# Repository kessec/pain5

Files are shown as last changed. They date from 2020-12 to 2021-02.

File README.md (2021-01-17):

## The Pain 5 Keyboard! 
Pain-5 Logo

A 5-key keyboard that depends on pressing keys in combination! Supports up to 120 keys and/or macros!

### Features
- Licensed under [Solderpad Hardware License v2.1](https://solderpad.org/licenses/SHL-2.1/)
- ATMEGA32U4 Based.
- USB-C Support.
- QMK compatible.
- One-handed operation.
- 0603 components (good for hand placing!).
- Comes with all the files for JLCPCB production.

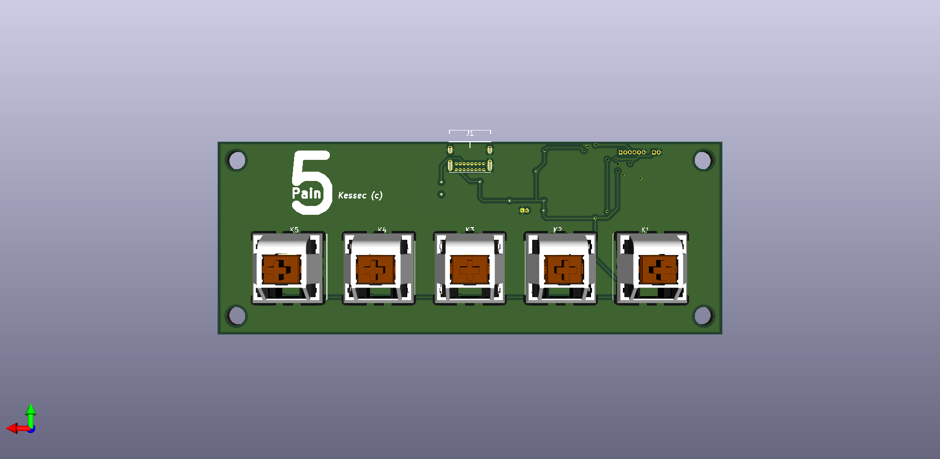
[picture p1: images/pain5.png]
3D Model Front

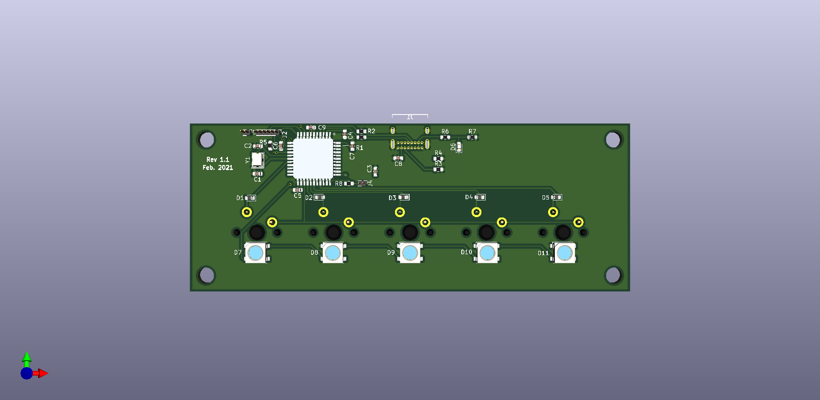
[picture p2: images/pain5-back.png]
3D Model Back


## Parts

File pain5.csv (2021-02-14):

Comment | Designator | Footprint | LCSC
22pF | C1,C2 | Capacitor_SMD:C_0603_1608Metric | C1653
10uF | C3 | Capacitor_SMD:C_0603_1608Metric | C96446
0.1uF | C4,C5,C6,C7 | Capacitor_SMD:C_0603_1608Metric | C170140
4.7uF | C8 | Capacitor_SMD:C_0603_1608Metric | C19666
1uF | C9 | Capacitor_SMD:C_0603_1608Metric | C15849
D_Schottky | D1,D2,D3,D4,D5 | Diode_SMD:D_0603_1608Metric | C316054
POWER_LED | D6 | LED_SMD:LED_0603_1608Metric | C72043
USB_C_Receptacle_USB2.0 | J1 | Type-C:USB_C_GCT_USB4085
ISP Programming | J2 | Connector_PinHeader_1.00mm:PinHeader_1x06_P1.00mm_Vertical
Reseter | J3 | Connector_PinHeader_1.00mm:PinHeader_1x02_P1.00mm_Vertical
KEYSW | K1,K2,K3,K4,K5 | Switch_Keyboard_Cherry_MX:SW_Cherry_MX_PCB_1.00u
22 | R1,R2 | Resistor_SMD:R_0603_1608Metric | C23345
5.1k | R3,R4 | Resistor_SMD:R_0603_1608Metric | C23186
10K | R5 | Resistor_SMD:R_0603_1608Metric | C25804
1K | R6 | Resistor_SMD:R_0603_1608Metric | C21190
2K | R7 | Resistor_SMD:R_0603_1608Metric | C22975
MCU-ATMEGA32U4-MUR(VQFN44) | U1 | ATMEGA-32U4-MUR:MCU-ATMEGA32U4-MUR_VQFN44 | C45874
Crystal_GND24 | Y1 | Crystal:Crystal_SMD_3225-4Pin_3.2x2.5mm | C13738

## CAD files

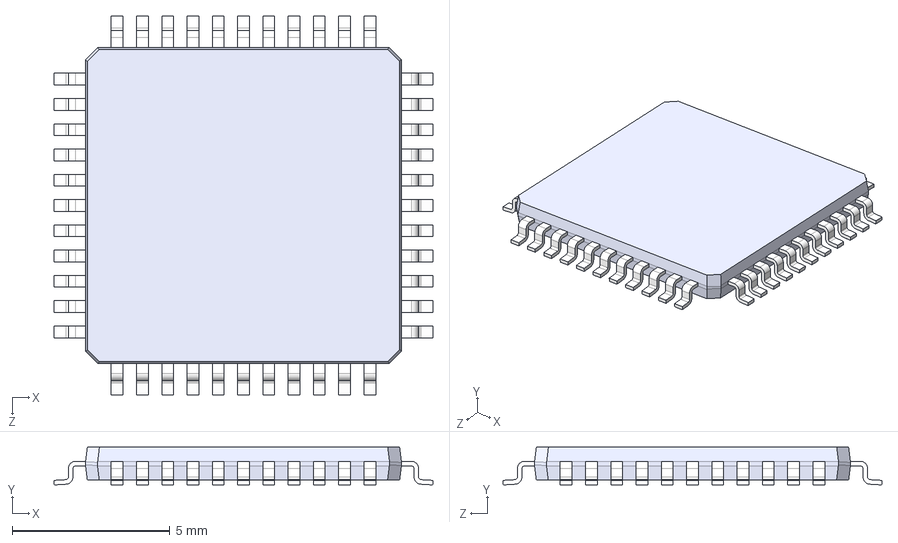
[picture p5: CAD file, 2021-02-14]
3D/ATMEGA32U4-AU.step
12.0 x 1.20 x 12.0 mm

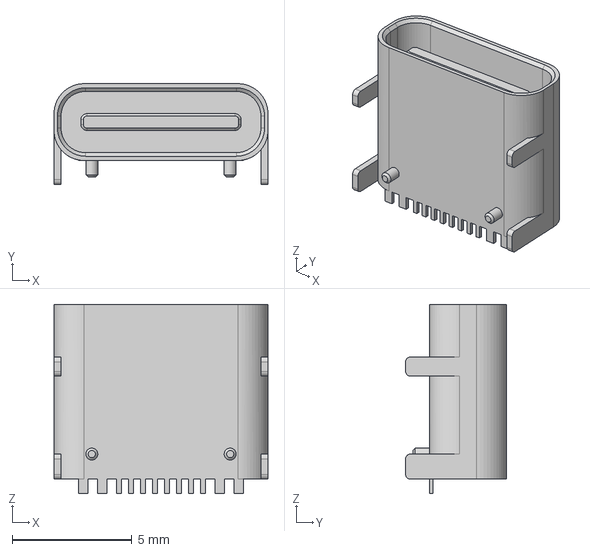
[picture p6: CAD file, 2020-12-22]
components/Type-C/HRO TYPE-C-31-M-12.step
8.94 x 4.21 x 7.90 mm

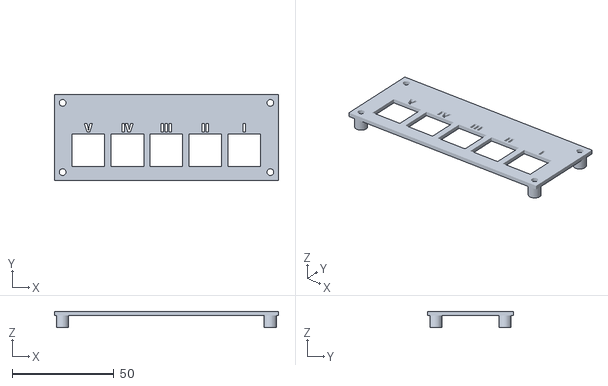
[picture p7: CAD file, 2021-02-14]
STL/Topv4.stl
110.0 x 42.0 x 8.00

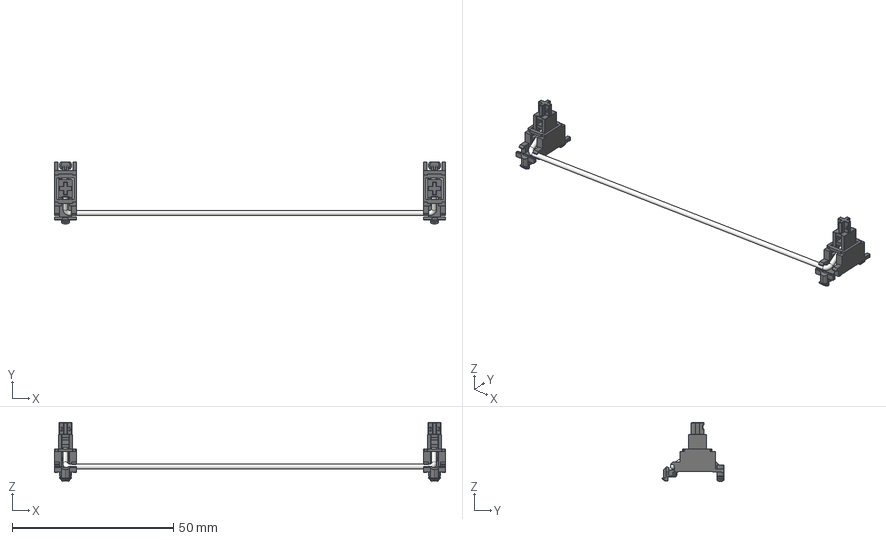
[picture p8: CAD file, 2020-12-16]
Switch_Keyboard/packages3d_src/Mounting_Keyboard_Stabilizer/Stabilizer_Cherry_MX_7u.FCStd
121.1 x 19.2 x 18.3 mm
Bar
Stabilizer_Key_
Stabilizer_Base_
Stabilizer_Key
Stabilizer_Base

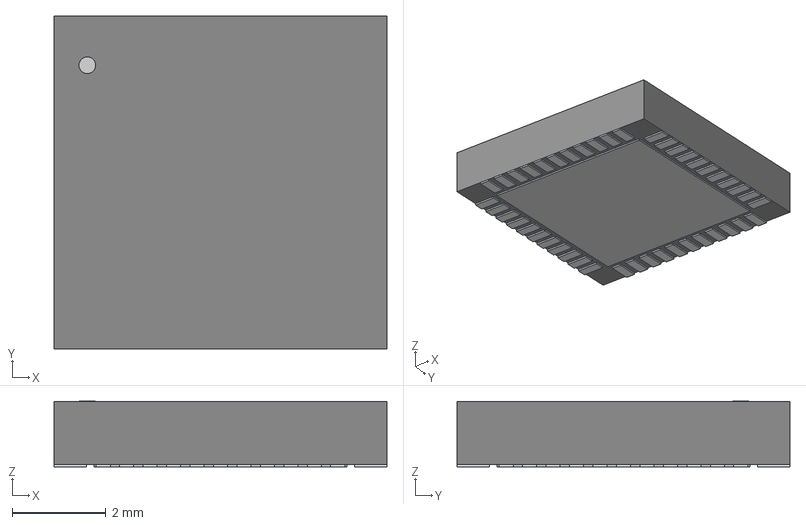
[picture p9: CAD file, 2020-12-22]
3D/44PW_ATM.step
7.10 x 7.10 x 1.40 mm

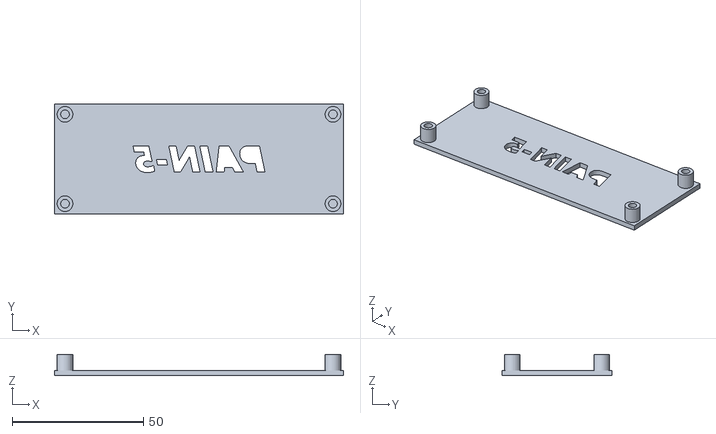
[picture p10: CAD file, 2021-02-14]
STL/Basev4.stl
110.0 x 42.0 x 8.00

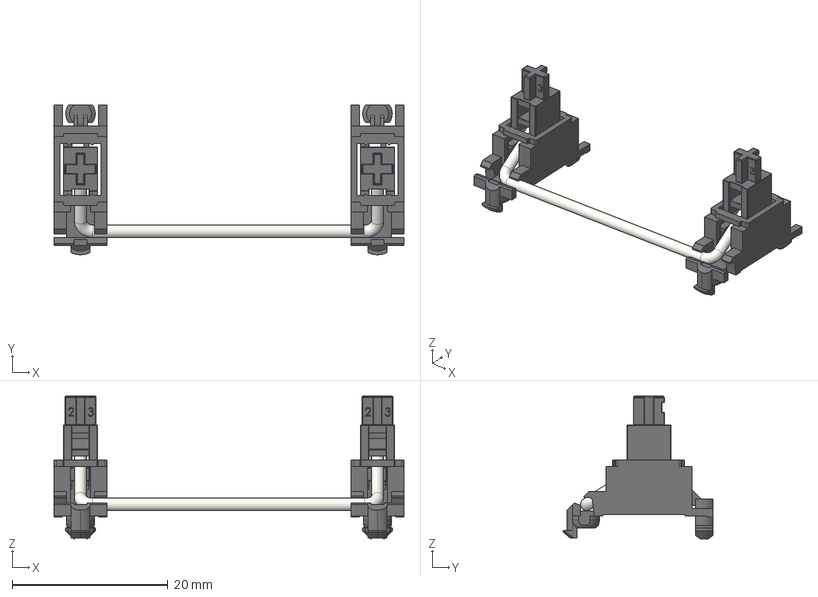
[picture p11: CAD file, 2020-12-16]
Switch_Keyboard/packages3d_src/Mounting_Keyboard_Stabilizer/Stabilizer_Cherry_MX_3u.FCStd
44.9 x 19.2 x 18.3 mm
Bar
Stabilizer_Key_
Stabilizer_Base_
Stabilizer_Key
Stabilizer_Base

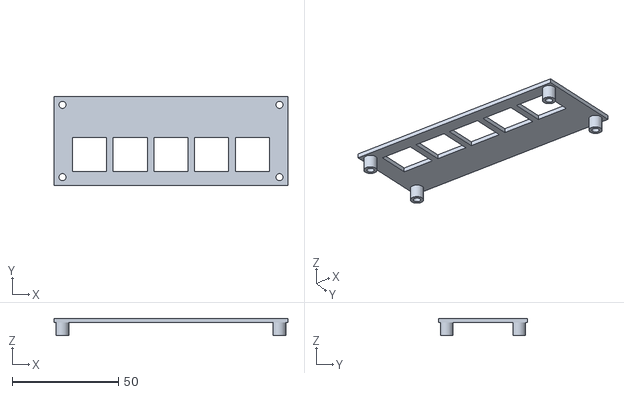
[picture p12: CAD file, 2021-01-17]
STL/Top.stl
110.0 x 42.0 x 8.00

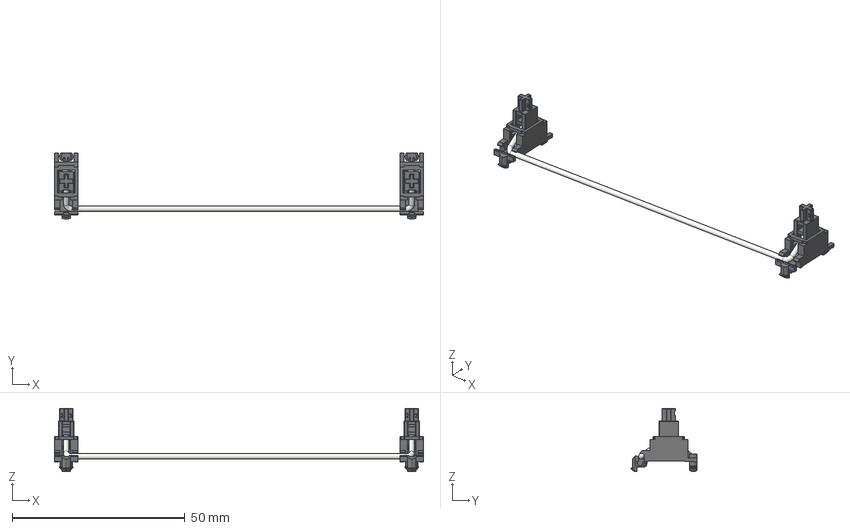
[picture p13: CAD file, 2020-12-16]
Switch_Keyboard/packages3d_src/Mounting_Keyboard_Stabilizer/Stabilizer_Cherry_MX_6.25u.FCStd
106.8 x 19.2 x 18.3 mm
Bar
Stabilizer_Key_
Stabilizer_Base_
Stabilizer_Key
Stabilizer_Base

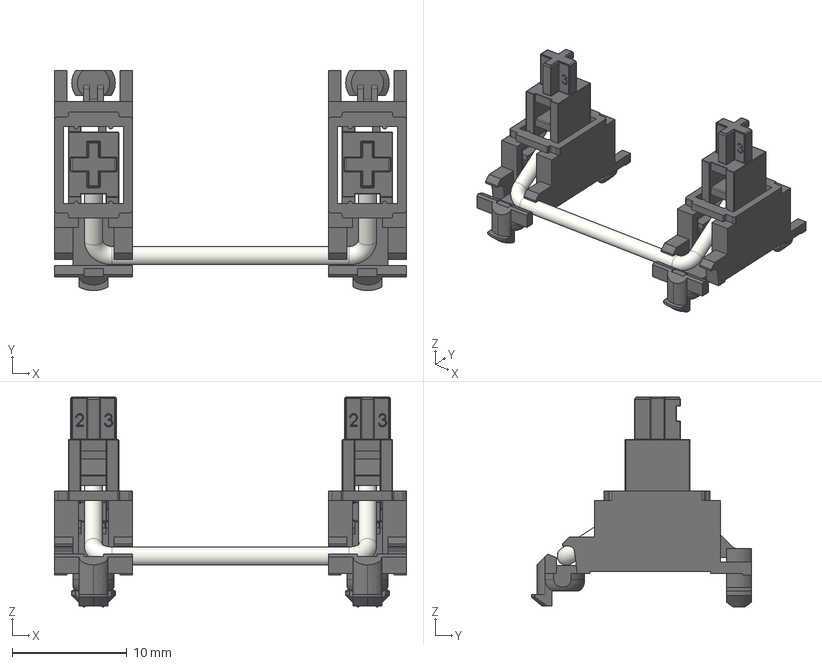
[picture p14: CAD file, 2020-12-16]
Switch_Keyboard/packages3d_src/Mounting_Keyboard_Stabilizer/Stabilizer_Cherry_MX_2u.FCStd
30.7 x 19.2 x 18.3 mm
Bar
Stabilizer_Key_
Stabilizer_Base_
Stabilizer_Key
Stabilizer_Base

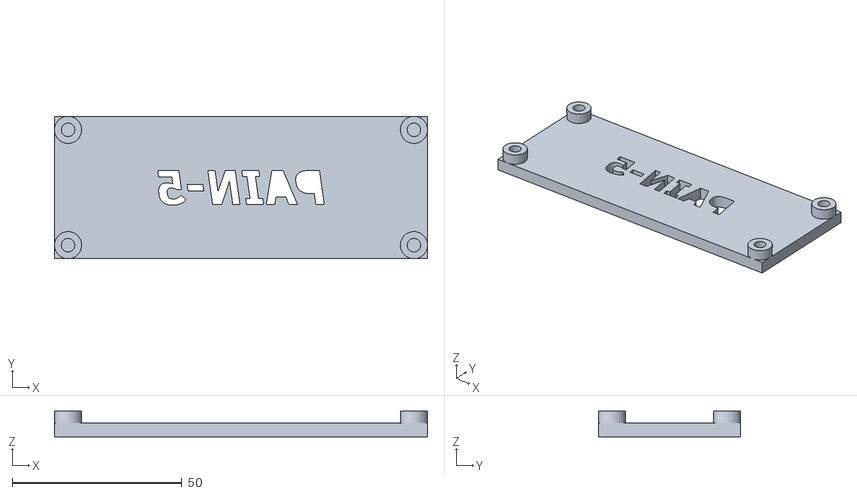
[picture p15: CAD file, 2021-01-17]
STL/Basev2.stl
110.0 x 42.0 x 7.55

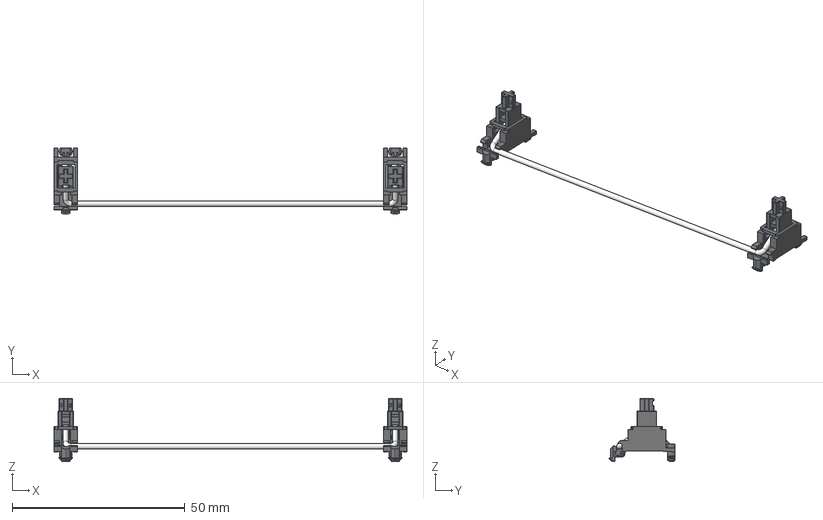
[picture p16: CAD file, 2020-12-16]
Switch_Keyboard/packages3d_src/Mounting_Keyboard_Stabilizer/Stabilizer_Cherry_MX_6u.FCStd
102.1 x 19.2 x 18.3 mm
Bar
Stabilizer_Key_
Stabilizer_Base_
Stabilizer_Key
Stabilizer_Base

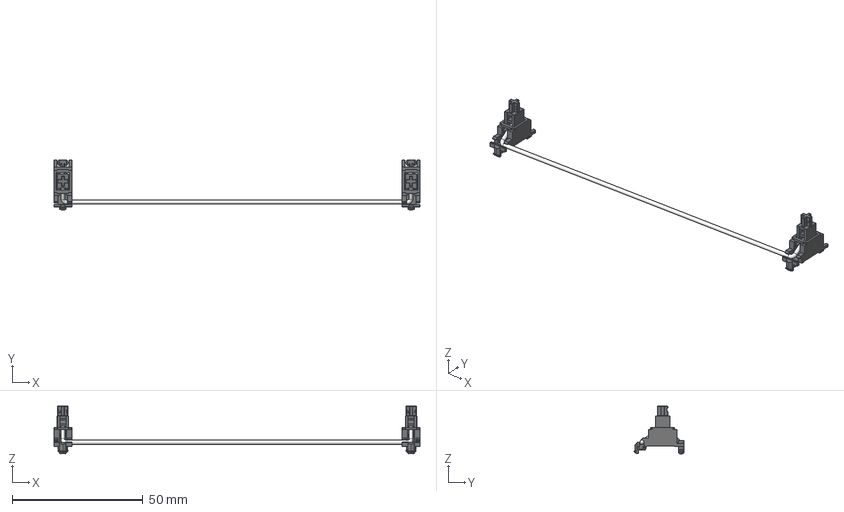
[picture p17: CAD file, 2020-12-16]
Switch_Keyboard/packages3d_src/Mounting_Keyboard_Stabilizer/Stabilizer_Cherry_MX_8u.FCStd
140.1 x 19.2 x 18.3 mm
Bar
Stabilizer_Key_
Stabilizer_Base_
Stabilizer_Key
Stabilizer_Base

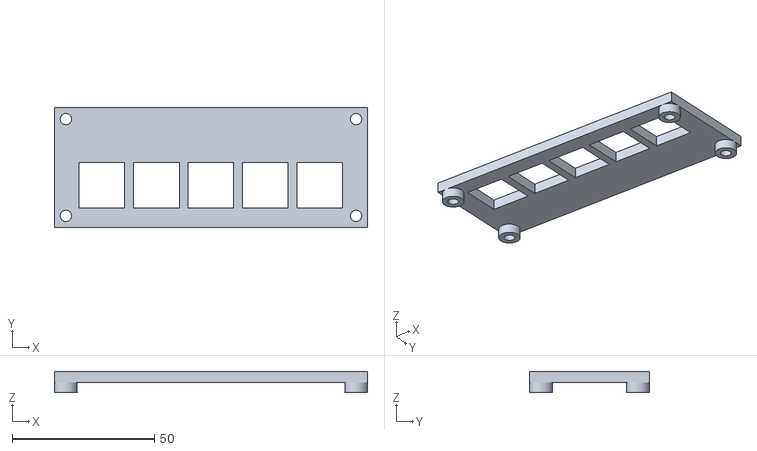
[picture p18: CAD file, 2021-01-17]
STL/Topv2.stl
110.0 x 42.0 x 7.55

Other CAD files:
STL/Basev3.stl
STL/Base.stl
STL/Topv3.stl

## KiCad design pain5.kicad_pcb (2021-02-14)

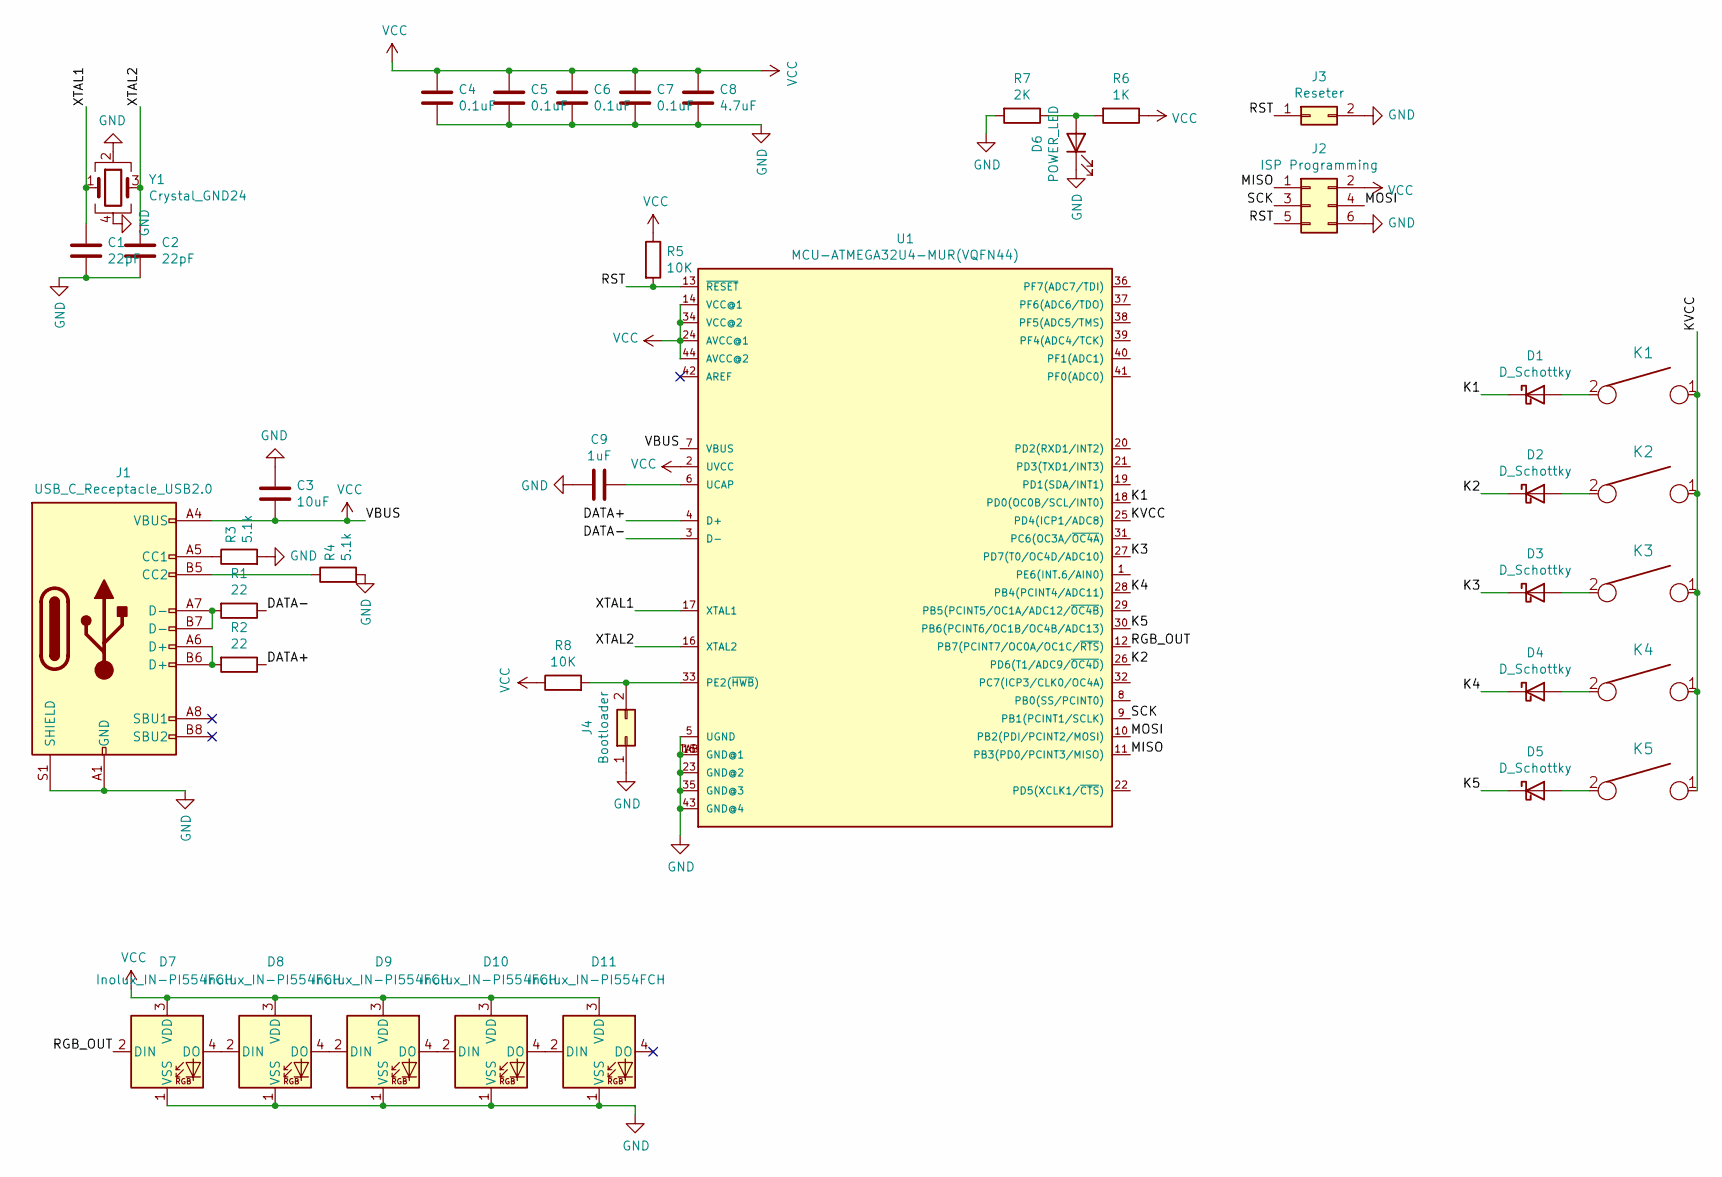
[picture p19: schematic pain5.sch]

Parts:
C1, C2: 22pF; C_0603_1608Metric; LCSC C1653
C3: 10uF; C_0603_1608Metric; LCSC C96446
C4, C5, C6, C7: 0.1uF; C_0603_1608Metric; LCSC C170140
C8: 4.7uF; C_0603_1608Metric; LCSC C19666
C9: 1uF; C_0603_1608Metric; LCSC C15849
D1, D2, D3, D4, D5: D_Schottky; D_0603_1608Metric; LCSC C316054
D6: POWER_LED; LED_0603_1608Metric; LCSC C72043
D7, D8, D9, D10, D11: Inolux_IN-PI554FCH; LED_Inolux_IN-PI554FCH_PLCC4_5.0x5.0mm_P3.2mm
J1: USB_C_Receptacle_USB2.0; USB_C_GCT_USB4085
J2: ISP Programming; PinHeader_1x06_P1.00mm_Vertical
J3: Reseter; PinHeader_1x02_P1.00mm_Vertical
J4: Bootloader; PinHeader_1x02_P1.00mm_Vertical
K1, K2, K3, K4, K5: KEYSW; SW_Cherry_MX_PCB_1.00u
R1, R2: 22; R_0603_1608Metric; LCSC C23345
R3, R4: 5.1k; R_0603_1608Metric; LCSC C23186
R5, R8: 10K; R_0603_1608Metric; LCSC C25804
R6: 1K; R_0603_1608Metric; LCSC C21190
R7: 2K; R_0603_1608Metric; LCSC C22975
U1: MCU-ATMEGA32U4-MUR(VQFN44); QFP80P1200X1200X120-44N; MPN ATMEGA32U4-MUR; LCSC C45874
Y1: Crystal_GND24; Crystal_SMD_3225-4Pin_3.2x2.5mm; LCSC C13738

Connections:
/DATA+: R2.1, U1.4 (D+)
/DATA-: R1.1, U1.3 (D-)
/K1: D1.1 (K), U1.18 (PD0(OC0B/SCL/INT0))
/K2: D2.1 (K), U1.26 (PD6(T1/ADC9/~OC4D))
/K3: D3.1 (K), U1.27 (PD7(T0/OC4D/ADC10))
/K4: D4.1 (K), U1.28 (PB4(PCINT4/ADC11))
/K5: D5.1 (K), U1.30 (PB6(PCINT6/OC1B/OC4B/ADC13))
/KVCC: K1.1, K2.1, K3.1, K4.1, K5.1, U1.25 (PD4(ICP1/ADC8))
/MISO: J2.1, U1.11 (PB3(PD0/PCINT3/MISO))
/MOSI: J2.4, U1.10 (PB2(PDI/PCINT2/MOSI))
/RGB_OUT: D7.2 (DIN), U1.12 (PB7(PCINT7/OC0A/OC1C/~RTS))
/RST: J2.5, J3.1, R5.2, U1.13 (~RESET)
/SCK: J2.3, U1.9 (PB1(PCINT1/SCLK))
/XTAL1: C1.1, U1.17 (XTAL1), Y1.1
/XTAL2: C2.1, U1.16 (XTAL2), Y1.3
GND: C1.2, C2.2, C3.2, C4.2, C5.2, C6.2, C7.2, C8.2, C9.2, D6.1 (K), D7.1 (VSS), D8.1 (VSS), D9.1 (VSS), D10.1 (VSS), D11.1 (VSS), J1.A1 (GND), J1.A12 (GND), J1.B1 (GND), J1.B12 (GND), J1.S1 (SHIELD), J2.6, J3.2, J4.1, R3.2, R4.2, R7.2, U1.5 (UGND), U1.15 (GND@1), U1.23 (GND@2), U1.35 (GND@3), U1.43 (GND@4), U1.TAB (GND@1), Y1.2, Y1.4
unnamed: C9.1, U1.6 (UCAP)
unnamed: D1.2 (A), K1.2
unnamed: D2.2 (A), K2.2
unnamed: D3.2 (A), K3.2
unnamed: D4.2 (A), K4.2
unnamed: D5.2 (A), K5.2
unnamed: D6.2 (A), R6.2, R7.1
unnamed: D7.4 (DO), D8.2 (DIN)
unnamed: D8.4 (DO), D9.2 (DIN)
unnamed: D9.4 (DO), D10.2 (DIN)
unnamed: D10.4 (DO), D11.2 (DIN)
unnamed: J1.A5 (CC1), R3.1
unnamed: J1.A6 (D+), J1.B6 (D+), R2.2
unnamed: J1.A7 (D-), J1.B7 (D-), R1.2
unnamed: J1.B5 (CC2), R4.1
unnamed: J4.2, R8.2, U1.33 (PE2(~HWB))
VCC: C3.1, C4.1, C5.1, C6.1, C7.1, C8.1, D7.3 (VDD), D8.3 (VDD), D9.3 (VDD), D10.3 (VDD), D11.3 (VDD), J1.A4 (VBUS), J1.A9 (VBUS), J1.B4 (VBUS), J1.B9 (VBUS), J2.2, R5.1, R6.1, R8.1, U1.2 (UVCC), U1.7 (VBUS), U1.14 (VCC@1), U1.24 (AVCC@1), U1.34 (VCC@2), U1.44 (AVCC@2)

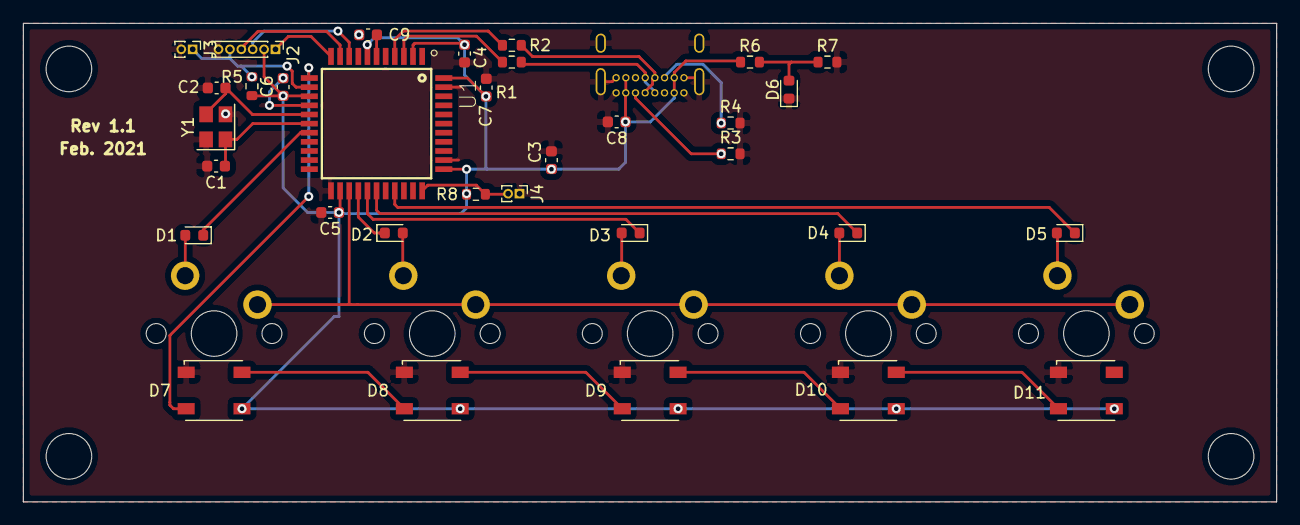
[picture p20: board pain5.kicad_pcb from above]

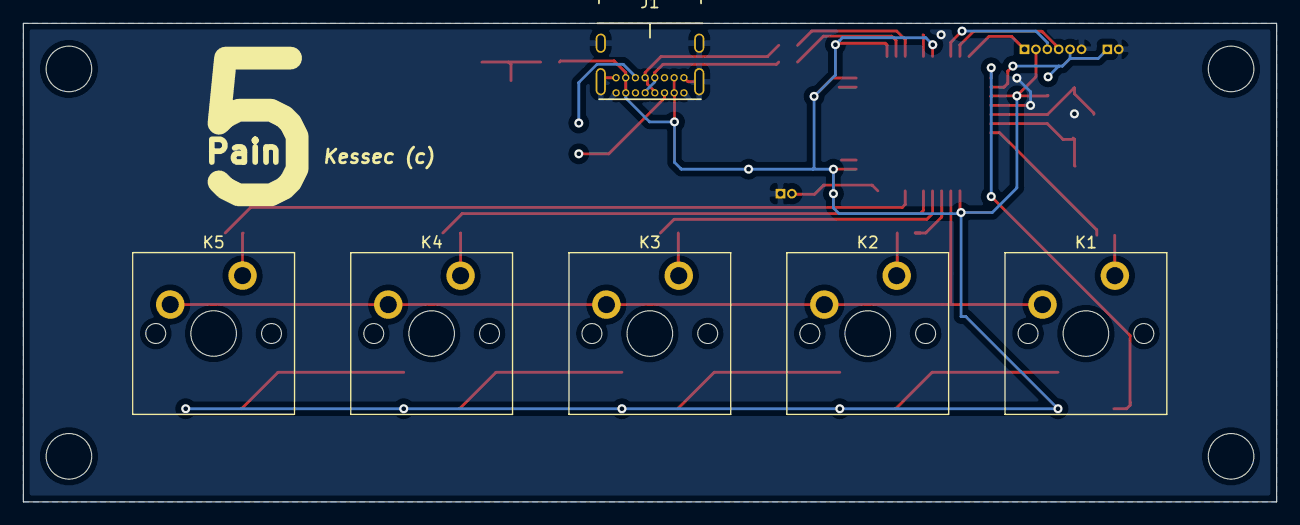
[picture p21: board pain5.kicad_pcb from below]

Board: 2 copper layers, 110.0 x 42.0 mm, 39 parts (6 on the bottom side), 33 nets.

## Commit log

2020-12-16 [upload] all the files im currently using
    [Stabilizer_Cherry_MX_2u.FCStd, Stabilizer_Cherry_MX_3u.FCStd, Stabilizer_Cherry_MX_6.25u.FCStd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]
2020-12-22 [tweak] i don't wanna write it all
    [44PW_ATM.step, HRO TYPE-C-31-M-12.step, pain5.sch]
2021-01-17 [upload] added a lot more
    [Base.stl, Basev2.stl, Basev3.stl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]
2021-02-14 [tweak] rgb update :)
    [ATMEGA32U4-AU.step, Basev4.stl, Topv4.stl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]
